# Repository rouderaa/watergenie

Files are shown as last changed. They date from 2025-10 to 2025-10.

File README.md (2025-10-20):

# ESP32 Water Genie

A smart water meter monitoring system built for the ESP32-S3 that tracks water consumption using a pulse-based sensor and provides remote access via Telnet.

## Overview

ESP32 Water Genie monitors water consumption by detecting pulses from a water meter's indicator using an optical or magnetic probe. The system logs timestamped readings and provides a command-line interface over Telnet for configuration and data retrieval.
It uses the position of the back of the red arrow of the watermeter to detect that another litre of water has been used.

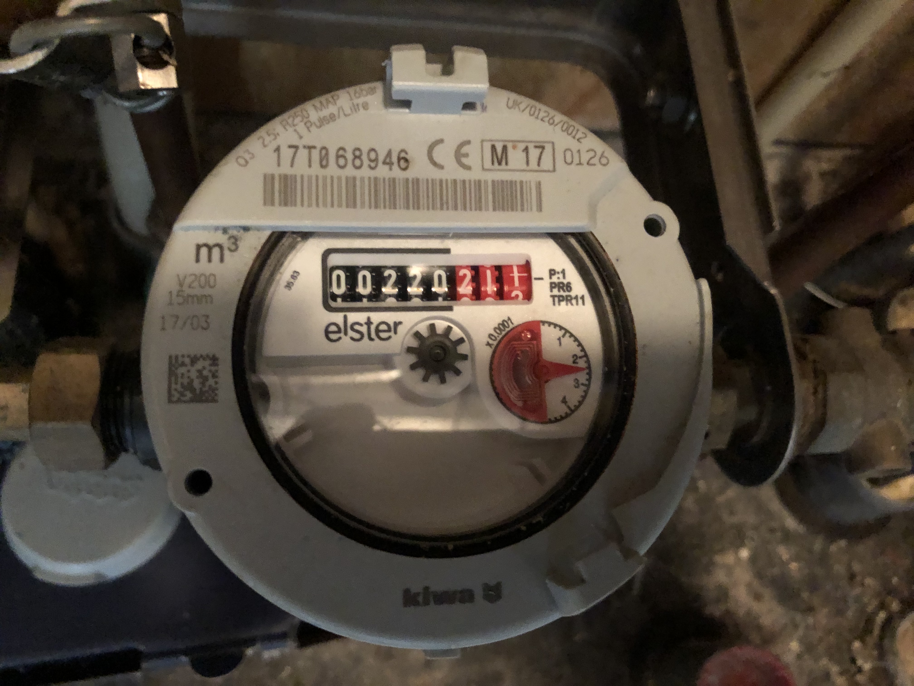
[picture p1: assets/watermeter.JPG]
Conventional water meter

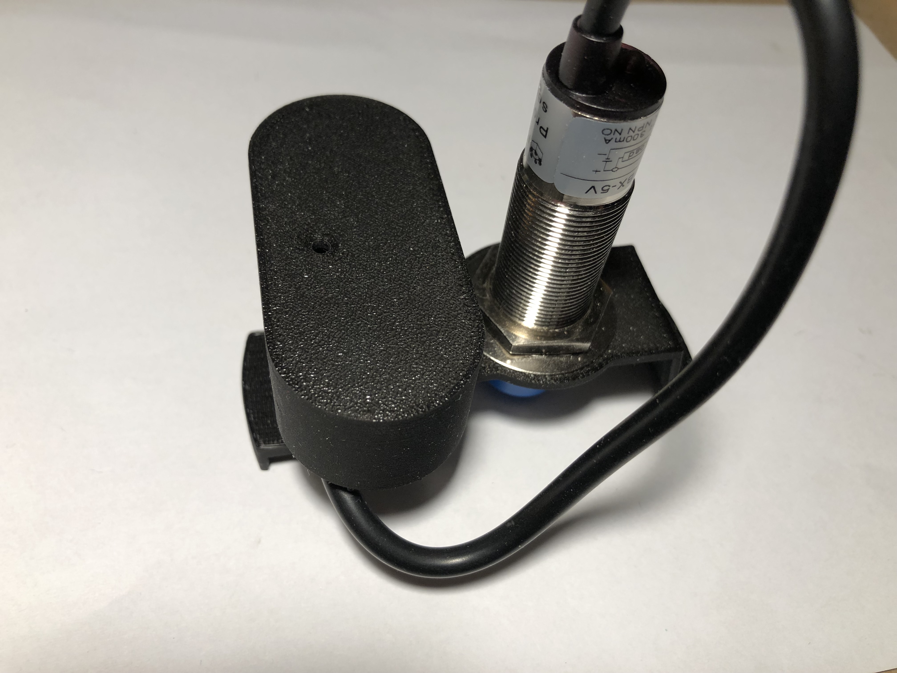
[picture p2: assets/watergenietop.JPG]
Top view watergenie

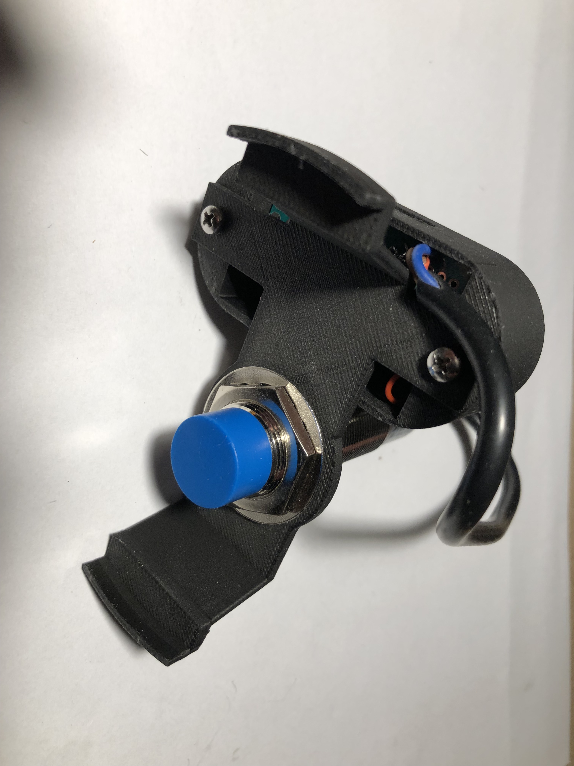
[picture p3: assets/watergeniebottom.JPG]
Bottom view watergenie


## Features

- **Real-time Water Monitoring**: Tracks water consumption with pulse detection (2 pulses per liter)
- **NTP Time Synchronization**: Automatically syncs with NTP servers for accurate timestamps
- **Data Logging**: Stores timestamped water consumption data
- **Telnet Interface**: Remote command-line access for monitoring and configuration
- **Visual Feedback**: RGB LED indicates sensor status and system activity
- **WiFi Connectivity**: Connects to your local network for remote access

## Hardware Requirements

- ESP32-S3 development board with RGB LED
- Water meter pulse sensor (hall sensor)
For example: 
M18 8mm detectie DC 5V NPN PNP NO NC LJ18A3-8-Z/BX
Connect a 1Kohm resistor to 3.3v and the detection line of the sensor since it has an open collector output.
- Sensor connected to GPIO pin 4

## Pin Configuration

| Pin | Function |
|-----|---|
| GPIO 4 | Water meter probe input |
| Built-in RGB LED | Status indicator |

## Installation

1. Clone this repository
2. Install required Arduino libraries:
   - WiFi (ESP32 core)
   - esp_system (ESP32 core)
3. Prepare your compiler for esp32s3 compilation:
    - Copy the files described in directory extra_platformio_board.
4. Compile using visual studio code for the esp32s3 target using 'Upload and monitor' in PlatformIO.
5. open a cmd windows and execute telnet to the ip address shown in your serial log of visual code.

## Usage

### Initial Setup

1. Power on the ESP32-S3
2. The device will connect to WiFi and display its IP address on the serial monitor
3. System time will automatically sync with `nl.pool.ntp.org`

### Connecting via Telnet

```bash
telnet <ESP32_IP_ADDRESS>
```

You'll be greeted with:
```
Welcome to project ESP32_Water_Genie
ESP32>
```

### Available Commands

| Command | Description |
|---|---|
| `led on` | Turn on the RGB LED (green) |
| `led off` | Turn off the RGB LED |
| `help` | Display help information |
| `reset` | Perform a hard reset of the ESP32-S3 |
| `set <value>` | Set the current water meter reading |
| `get` | Display the current water meter reading |
| `time` | Display current date and time |
| `clear` | Clear the water log |
| `log` | Display logged water meter values with timestamps |

### Example Session

```
ESP32> get
Meter value: 1523

ESP32> time
2025-10-19 14:32:45

ESP32> log
[CSV output of timestamped readings]

ESP32> set 1500
ESP32> get
Meter value: 1500
```

## How It Works

### Pulse Detection

- The system monitors GPIO pin 4 for changes in the probe state
- Each transition (high to low or low to high) represents a pulse
- Two pulses equal one liter of water consumption
- The RGB LED flashes blue when the sensor detects the meter indicator

### Data Logging

- Each time the meter reading increments by one liter, a timestamped entry is logged
- Logs can be retrieved in CSV format via the `log` command
- Logs can be cleared using the `clear` command

### Time Synchronization

- On startup, the system connects to `nl.pool.ntp.org`
- Time zone is set to GMT+1 with automatic DST adjustment
- Timestamps use the format: `YYYY-MM-DD HH:MM:SS`

## LED Status Indicators

| Color | Status |
|---|---|
| Blue (flashing) | Water meter pulse detected |
| Green | LED manually turned on via command |
| Off | Normal operation / LED turned off |

## Network Configuration

- Protocol: Telnet (port 23)
- WiFi Mode: Station (STA)
- Single client connection supported

## Troubleshooting

**Cannot connect via Telnet**
- Verify the ESP32-S3 is connected to WiFi (check serial monitor)
- Ensure you're on the same network
- Try pinging the ESP32's IP address

**Time not syncing**
- Check internet connectivity
- Verify NTP server is accessible
- The system retries up to 10 times on startup

**Pulse detection not working**
- Verify sensor is connected to GPIO 4
- Check sensor power supply
- Ensure sensor is properly positioned near the water meter indicator

**Incorrect readings**
- Use the `set` command to calibrate the current meter reading
- Readings are stored as pulses (2 per liter) internally

## Technical Details

- **Pulse Resolution**: 0.5 liters (2 pulses per liter)
- **Scan Rate**: 10 Hz (probe checked 10 times per second)
- **Serial Baud Rate**: 115200
- **Time Zone**: GMT+1 (Central European Time) with DST

## Contributing

This project uses a custom command parser built with Flex/Bison. Contributions should maintain compatibility with the existing command structure.

## License

See license.txt.

## Author

Rob vd Ouderaa (rouderaa@hccnet.nl)

## Acknowledgments

- NTP time synchronization using ESP32 time libraries
- Telnet server implementation based on ESP32 WiFi libraries

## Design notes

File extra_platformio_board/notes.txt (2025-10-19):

In order to use the esp32s3-zero which has 4MB memory
do this:

- Put file esp32-s3-devkitc-1_4mb.json
in your directory:
.platformio/platforms/espressif32/boards

- Put file default_4MB.csv
in your directory:
.platformio/packages/framework-arduinoespressif32/tools/partitions

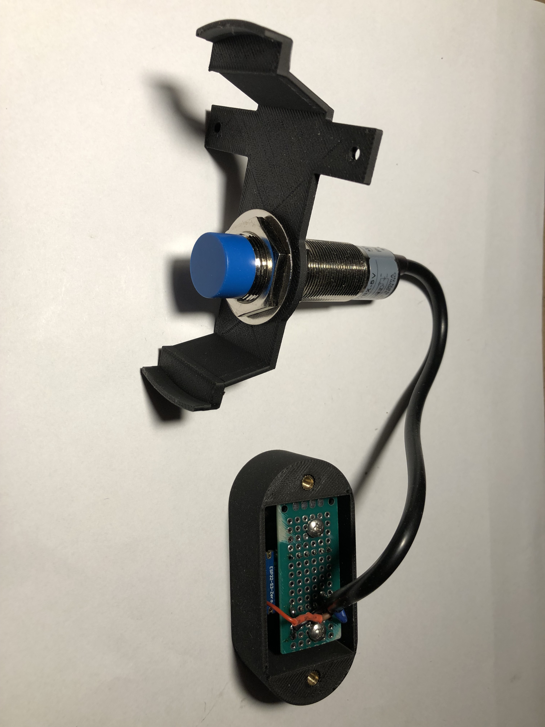
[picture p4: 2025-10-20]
assets/watergenieinside.JPG

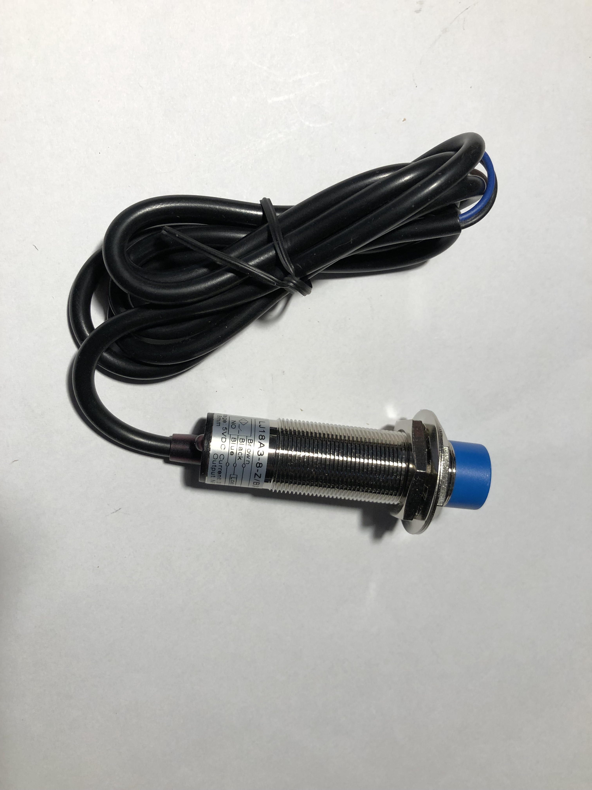
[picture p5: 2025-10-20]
assets/sensor.JPG

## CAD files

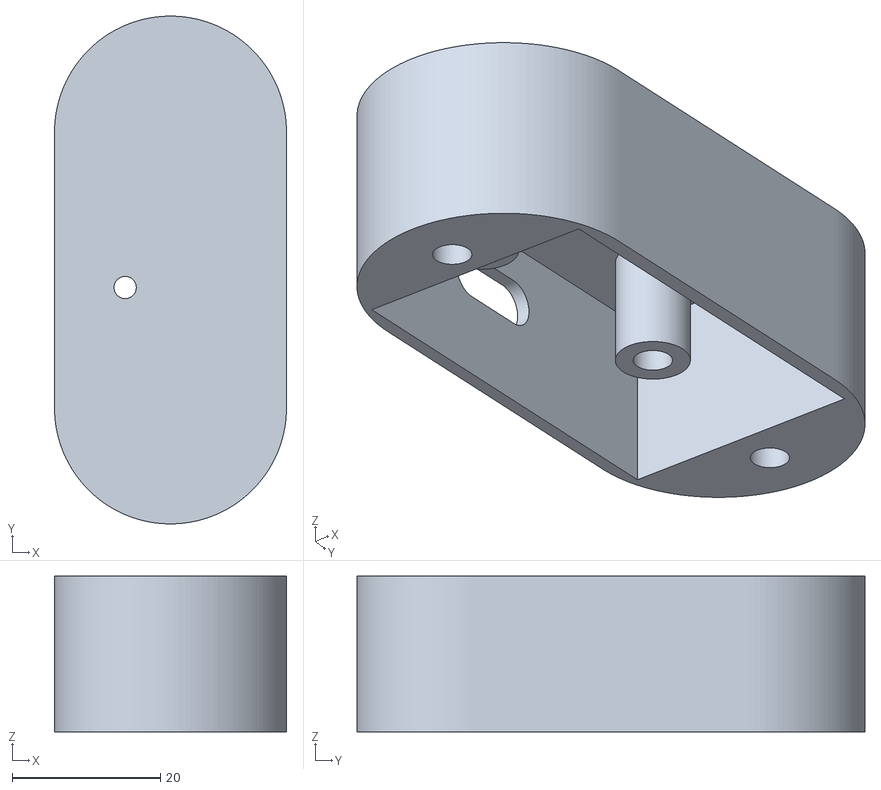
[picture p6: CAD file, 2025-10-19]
3ddesign/watergenie-fullCase002.stl
31.3 x 68.4 x 21.0

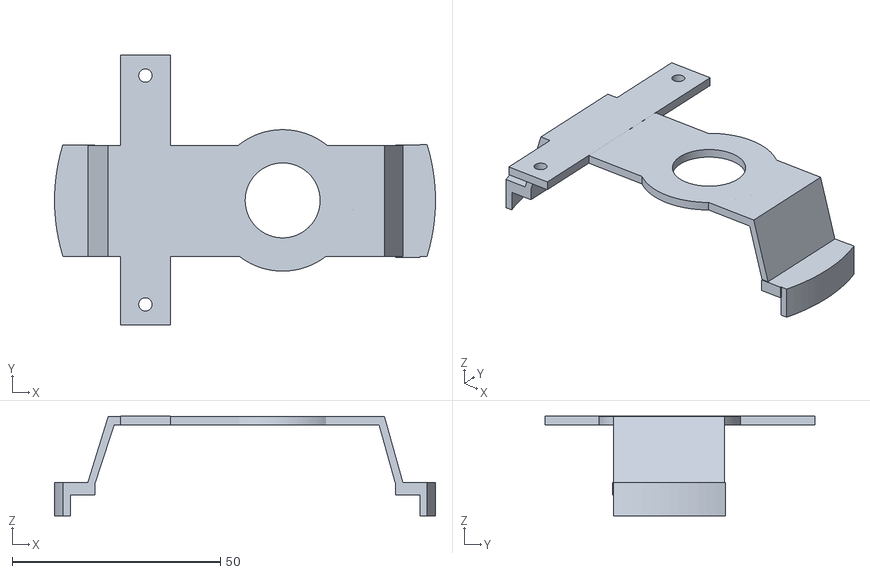
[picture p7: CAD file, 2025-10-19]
3ddesign/watergenie-fullBracket001.stl
91.6 x 65.0 x 24.0

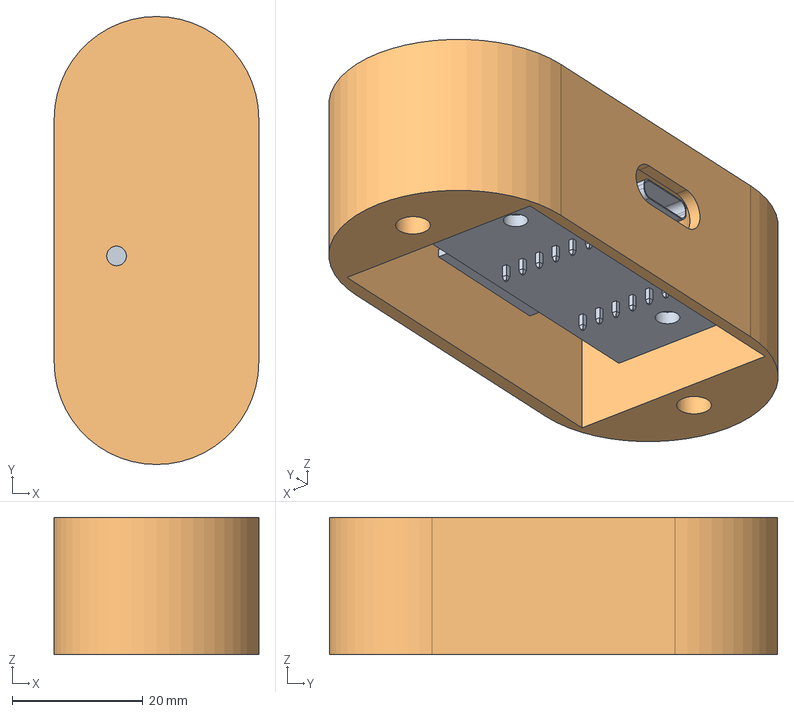
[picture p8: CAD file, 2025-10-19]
3ddesign/watergenie.FCStd
31.3 x 68.4 x 21.0 mm
mainCpu001
fullCase002

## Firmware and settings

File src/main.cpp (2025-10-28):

#include <Arduino.h>
#include <WiFi.h>
#include <esp_system.h>
#include "credentials.h"
#include <time.h>
#include <sys/time.h>
#include "waterlog.hpp"

HardwareSerial Serial1(1); // HACK

WiFiServer telnetServer(23);
WiFiClient telnetClient;

#define MAX_USER_INPUT 256
#define PROBE_PIN 4

extern void setup_led();
extern void set_led(unsigned char red, unsigned char green, unsigned char blue);

// water meter status
static ulong meter_reading;
static ulong meter_reading_previous;
static ulong meter_pulses;
static int meter_probe_current;
static int meter_probe_previous;
// NTP server configuration
const char* ntpServer = "nl.pool.ntp.org";
const long gmtOffset_sec = (3600*1);    // GMT offset in seconds (0 for UTC)
const int daylightOffset_sec = 3600;    // Daylight saving offset (3600 = 1 hour)

void printLocalTime(); // forward declaration

WaterLog waterlog;

extern "C"
{
    int yywrap();
    int yylex();
    char *set_input_string(const char *str);


    void handleLedOn()
    {
        Serial.println("LED ON");
        set_led(0, 50, 0);
    }
    void handleLedOff()
    {
        Serial.println("LED OFF");
        set_led(0, 0, 0);
    }
    void handleHelp()
    {
        telnetClient.println("led [on|off] : set the color led on the esp32-s3 to show blue.");
        telnetClient.println("help : displays this help information.");
        telnetClient.println("reset : performs a hard reset of the esp32-s3.");
        telnetClient.println("set <value> : sets the current value of the water meter.");
        telnetClient.println("get : returns the current value of the water meter.");
        telnetClient.println("time : displays the current date and time as retrieved from timeserver.");
        telnetClient.println("clear : clears the water log.");
        telnetClient.println("log : returns the latest measured water meter values with timestamp.");
    }

    /**
     * Converts two hexadecimal characters to their integer value
     * @param hexChars Pointer to two hex characters (0-9, A-F, a-f)
     * @return Integer value of the hexadecimal pair, or -1 if invalid characters
     */
    int hexPairToInt(const char *hexChars)
    {
        if (hexChars == NULL)
        {
            return -1;
        }

        int result = 0;

        // Process both characters using the same logic
        for (int i = 0; i < 2; i++)
        {
            char c = hexChars[i];
            int val;

            if (c >= '0' && c <= '9')
            {
                val = c - '0';
            }
            else if (c >= 'A' && c <= 'F')
            {
                val = c - 'A' + 10;
            }
            else if (c >= 'a' && c <= 'f')
            {
                val = c - 'a' + 10;
            }
            else
            {
                return -1; // Invalid character
            }

            // For first character, shift left by 4, for second just add
            result = (i == 0) ? (val << 4) : (result | val);
        }

        return result;
    }

    void handleReset()
    {
        esp_restart();
    }

    void handleSet(ulong value) {
        meter_reading = value;
        meter_pulses = meter_reading << 1;
    }

    void handleGet() {
        Serial.printf("Meter value:%lu\n", meter_reading);
        telnetClient.printf("Meter value:%lu\n", meter_reading);
    }

    void handleTime() {
        printLocalTime();
    }

    void handleClear() {
        waterlog.clear();
    }

    void handleLog() {
        waterlog.dumpCSVToTelnet(telnetClient);
    }

}

/**
 * Print current local time
 */
void printLocalTime() {
    struct tm timeinfo;
    if (!getLocalTime(&timeinfo)) {
        Serial.println("Failed to obtain time");
        return;
    }
    
    // Print in custom format
    char timeString[80];
    strftime(timeString, sizeof(timeString), "%Y-%m-%d %H:%M:%S\n", &timeinfo);

    telnetClient.printf(timeString);
}

/**
 * Synchronize ESP32-S3 system time with NTP server
 * @return true if successful, false otherwise
 */
bool syncTimeWithNTP() {
    Serial.println("Synchronizing time with NTP server...");
    
    // Configure time with NTP server
    configTime(gmtOffset_sec, daylightOffset_sec, ntpServer);
    
    // Wait for time to be set
    int retry = 0;
    const int maxRetries = 10;
    
    while (retry < maxRetries) {
        time_t now = time(nullptr);
        if (now > 24 * 3600) {  // Check if time is set (after Jan 1, 1970)
            Serial.println("Time synchronized successfully!");
            printLocalTime();
            return true;
        }
        Serial.print(".");
        delay(1000);
        retry++;
    }
    
    Serial.println("\nFailed to synchronize time");
    return false;
}

void setup()
{
    Serial.begin(115200);

    Serial.println("Initializing....");
    
    // Configure static IP before WiFi.begin()
    if (!WiFi.config(local_IP, gateway, subnet, primaryDNS, secondaryDNS)) {
        Serial.println("STA Failed to configure");
    }
    WiFi.begin(ssid, password);

    // Wait for connection
    while (WiFi.status() != WL_CONNECTED) {
        delay(500);
        Serial.print(".");
    }
    Serial.println();

    setup_led();
    syncTimeWithNTP();

    // Setup input for the probe
    pinMode(PROBE_PIN, INPUT);
    meter_probe_current = digitalRead(PROBE_PIN);
    meter_probe_previous = meter_probe_current;

    telnetServer.begin();
}

static bool showIp = true;
static const char *welcome = "Welcome to project ESP32_Water_Genie";
static const char *prompt = "ESP32> ";
static long timestamp = 0L;

static void scanProbe() {
    if (millis() > timestamp) {
        // 10 times per second
        timestamp = millis() + 100;
        meter_probe_current = digitalRead(PROBE_PIN);
        // Find out if there was a change in the probe
        if (meter_probe_current != meter_probe_previous) {
            // Show status led on the esp32-s3 board
            if (meter_probe_current == 0) {
                // sensor is detecting water meter indicator
                set_led(0,0,50);
            } else {
                set_led(0,0,0);
            }

            // Increase measured amount of pulses, two per litre
            meter_pulses++;             
            meter_reading = meter_pulses >> 1;
            
            if (meter_reading != meter_reading_previous) {
                // Store latest changed water meter value in log
                time_t now;
                time(&now);
                waterlog.add(now, meter_reading);

                meter_reading_previous = meter_reading;
            }

            meter_probe_previous = meter_probe_current;
        }
    }
}

void loop()
{
    scanProbe();

    if (telnetServer.hasClient())
    {
        // Handle incoming connection
        telnetClient = telnetServer.accept();
        showIp = false;
        // Purge initial characters from telnet, may contain rubish
        while(telnetClient.available()) {
            telnetClient.read();
        }
        Serial.println(welcome);
        telnetClient.println(welcome);
        telnetClient.print(prompt);
    }

    // Check for client disconnections
    if (!telnetClient || !telnetClient.connected())
    {
        // Reset the telnetClient object to its original state
        telnetClient.stop();
        showIp = true;
    }

    if (showIp)
    {
        // Keep displaying ip address on serial if not connected
        Serial.print("IP Address: ");
        Serial.println(WiFi.localIP());
        delay(1000);
    }

    if (telnetClient && telnetClient.connected())
    {
        static char inputBuffer[MAX_USER_INPUT];
        static int inputIndex = 0;

        while (telnetClient.available())
        {
            char c = telnetClient.read();
            if (c == '\n')
            {
                if (inputIndex > 0)
                {
                    inputBuffer[inputIndex] = '\0';
                    char *parseError = set_input_string(inputBuffer);
                    telnetClient.println(parseError);
                    inputIndex = 0;
                    telnetClient.print(prompt);
                }
                else
                {
                    // Empty line, just show prompt again
                    telnetClient.print(prompt);
                }
            }
            else if (inputIndex < MAX_USER_INPUT - 1)
            {
                if (c != '\r')
                    inputBuffer[inputIndex++] = c;
            }
        }
    }
}
